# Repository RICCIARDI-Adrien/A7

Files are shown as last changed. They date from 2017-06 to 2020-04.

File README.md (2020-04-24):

# A7

A hand-made computer based on a 8-bit PIC18F26K22 microcontroller.

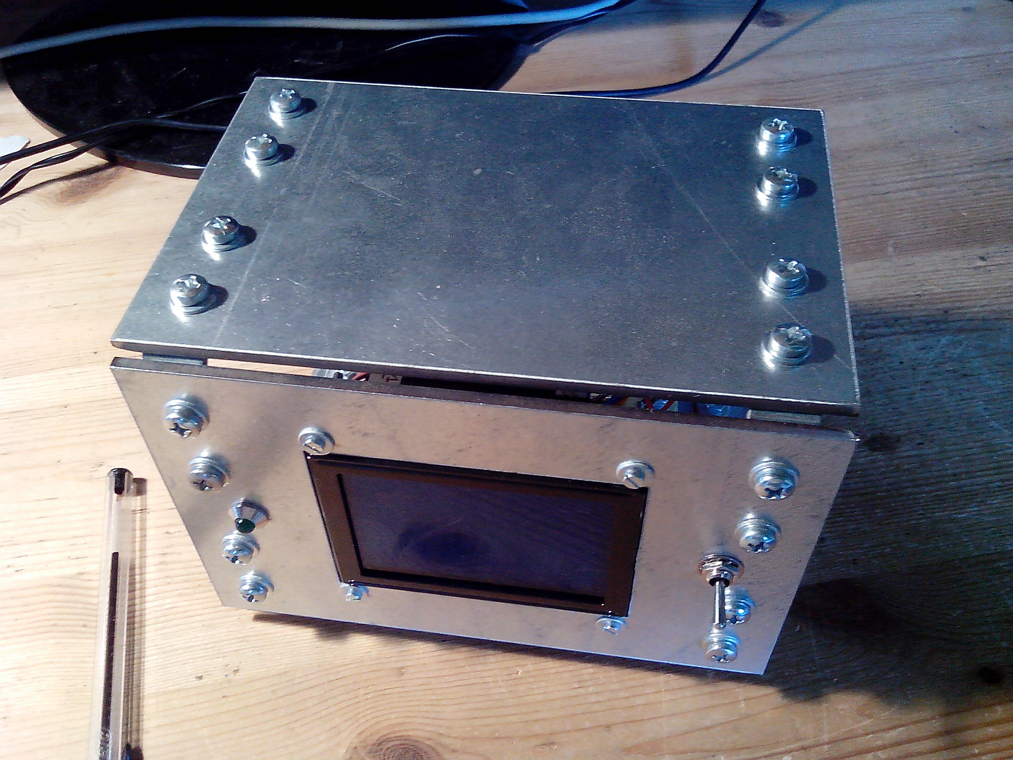
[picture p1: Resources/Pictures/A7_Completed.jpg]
A7


## Specifications

### CPU

* 64MHz PIC18 core (up to 16MIPS).
* 3896 RAM bytes.
* 32768 16-bit instruction words.

### Display

* 128x64 STN display with white pixels on blue backlight.
* 8-bit data interface with the microcontroller.

### Input

* Standard PS/2 keyboard support.
* Connect via standard PS/2 6-pin mini DIN connector.

### External storage

* On-board 128KB EEPROM (256-byte pages, 6ms maximum to write a page).
* Connected to a fast 4MHz SPI bus (less than 600us to read a full 256-byte page).

### Communication

* Standard RS-232 DB9 connector.
* Communication settings : 115200 bauds, no parity, one stop bit.

### Power supply

* Standard power supply jack.
* Input voltage from 7V to 24V with at least 200mA.
* Polarity reversal protection.

# Hardware

Schematics and PCB have been made with Eagle 7.5.  

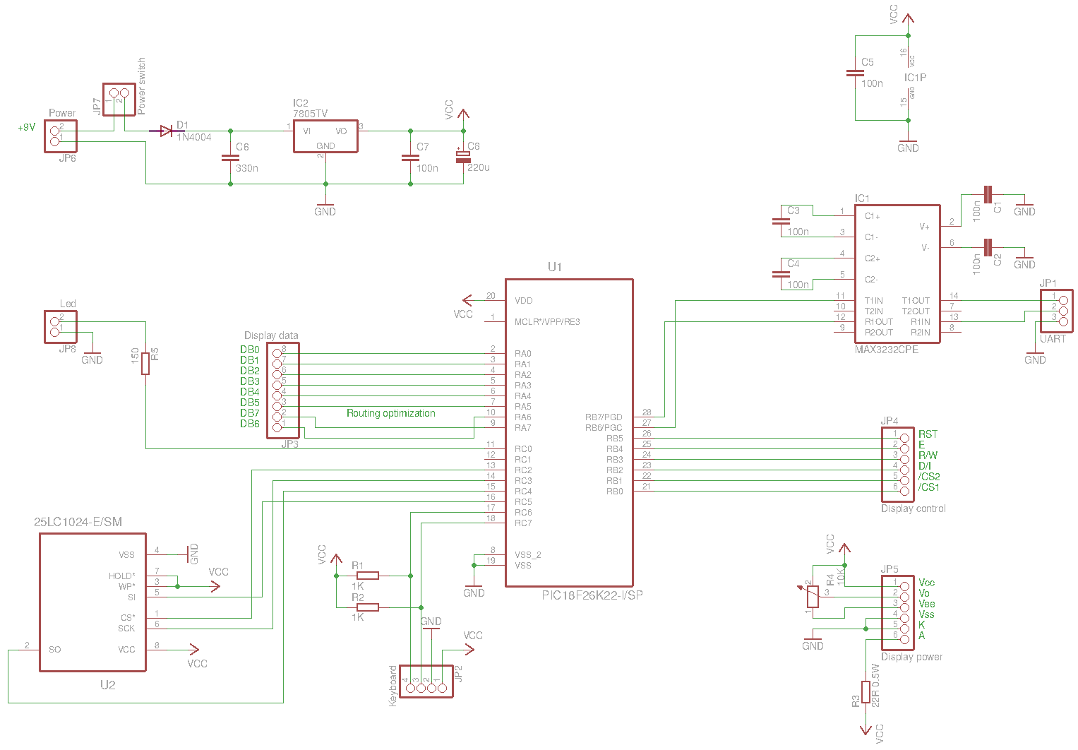
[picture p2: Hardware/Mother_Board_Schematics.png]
Motherboard schematics

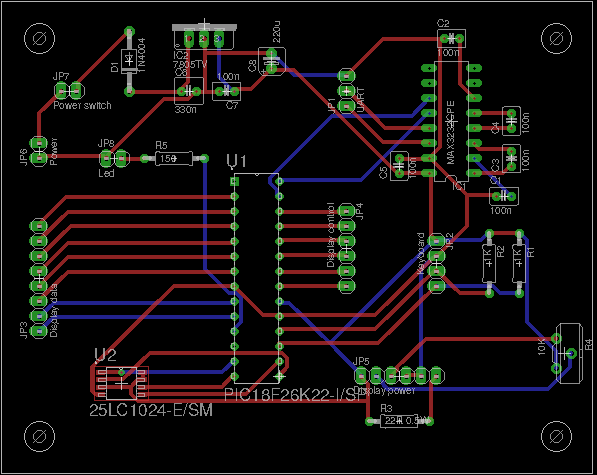
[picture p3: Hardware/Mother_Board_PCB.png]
Motherboard PCB


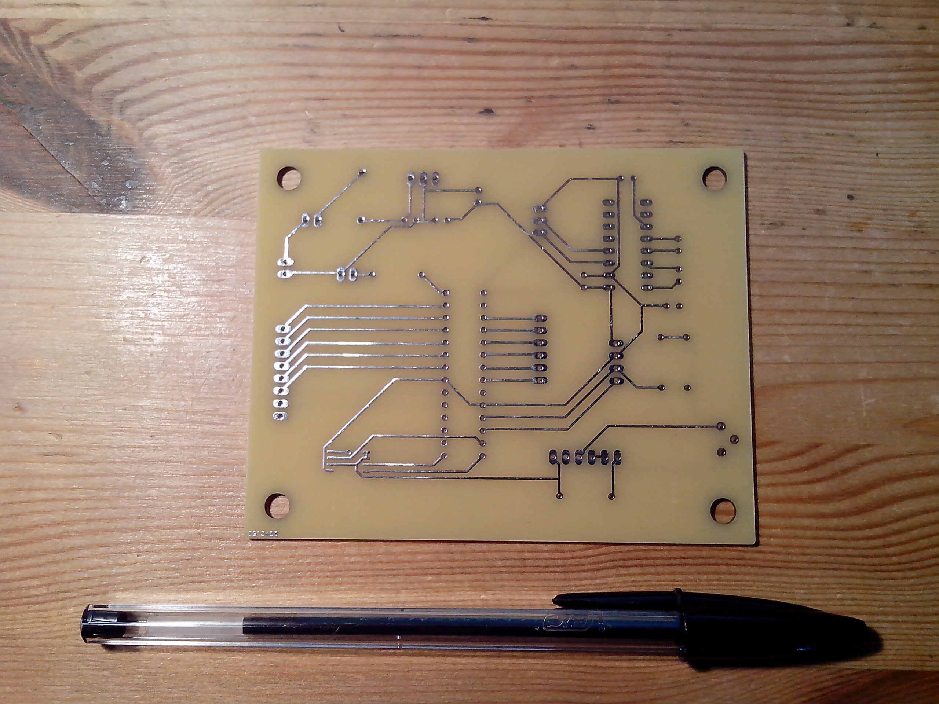
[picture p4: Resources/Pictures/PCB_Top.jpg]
Motherboard manufactured PCB (top view)

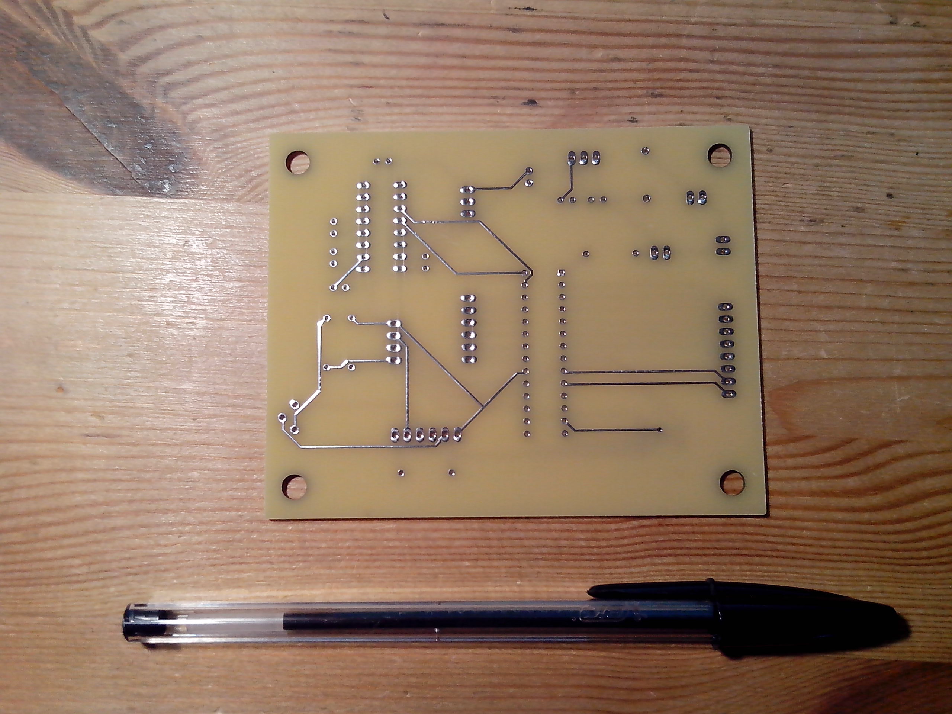
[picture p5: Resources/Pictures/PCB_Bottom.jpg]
Motherboard manufactured PCB (bottom view)

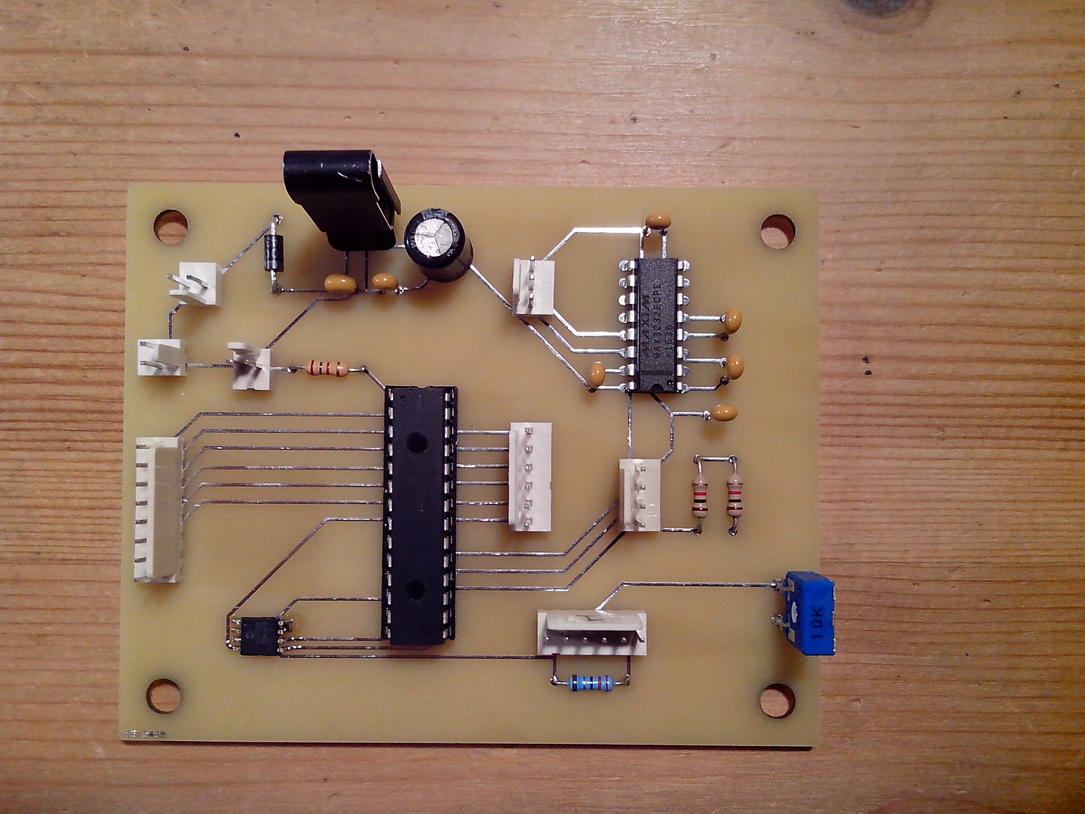
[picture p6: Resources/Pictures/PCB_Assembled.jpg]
Motherboard manufactured and assembled PCB


# Software

Use Microchip XC8 compiler to build software.  
You have to add the following environment variable for the build system to find the compiler-provided include files :
```
XC8_INCLUDES_PATH
```
The variable content must be the full path to the XC8 include directory. Below is an example for a Windows machine (don't forget to add quotation marks if the path contains spaces) :
```
"C:\Program Files\Microchip\xc8\v1.42\include"
```
  
In order to download applications on the A7, you have to set the following environment variable with the serial port device used to communicate with the A7 (like /dev/ttyS0, /dev/ttyUSB0...) :
```
A7_APPLICATION_DOWNLOAD_SERIAL_PORT_DEVICE
```

# Casing

Casing panels have been drawn with LibreCAD.

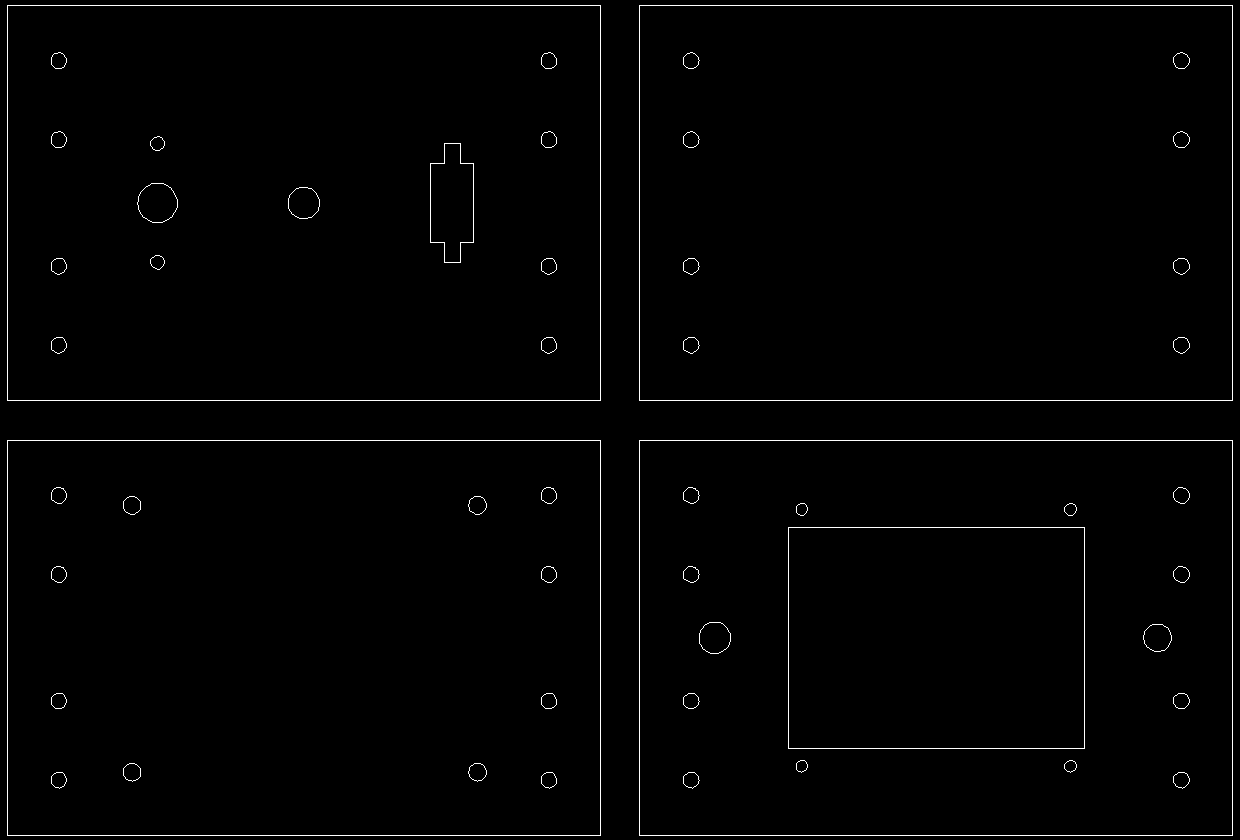
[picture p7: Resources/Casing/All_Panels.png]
Casing panels


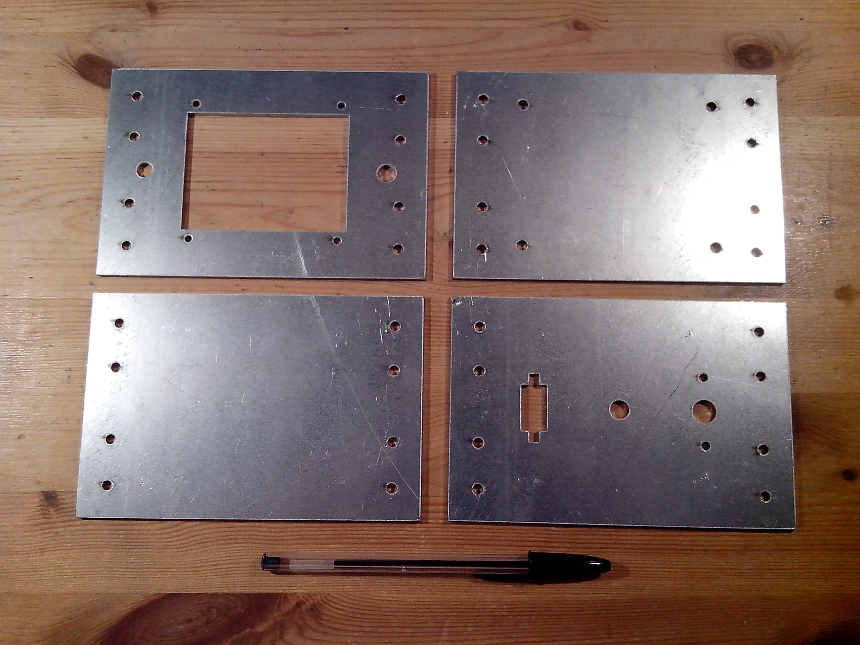
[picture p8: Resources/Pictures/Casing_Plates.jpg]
Casing plates

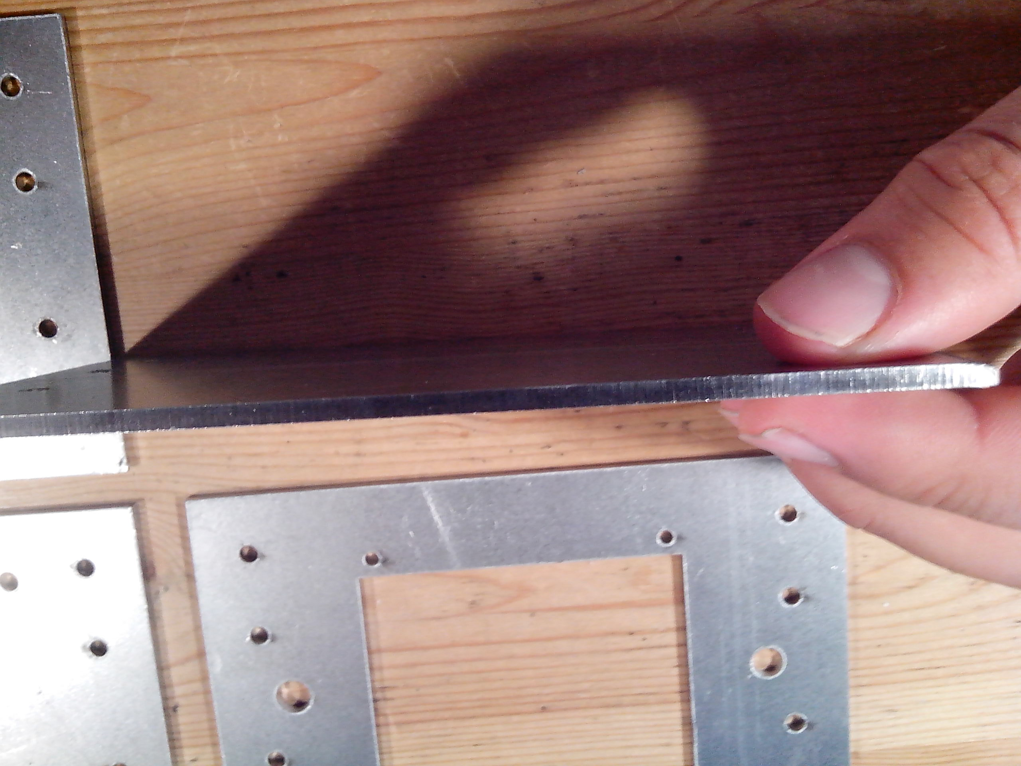
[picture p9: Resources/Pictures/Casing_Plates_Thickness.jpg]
Casing plates thickness


# Photo gallery

## 128x64 pixels graphical display

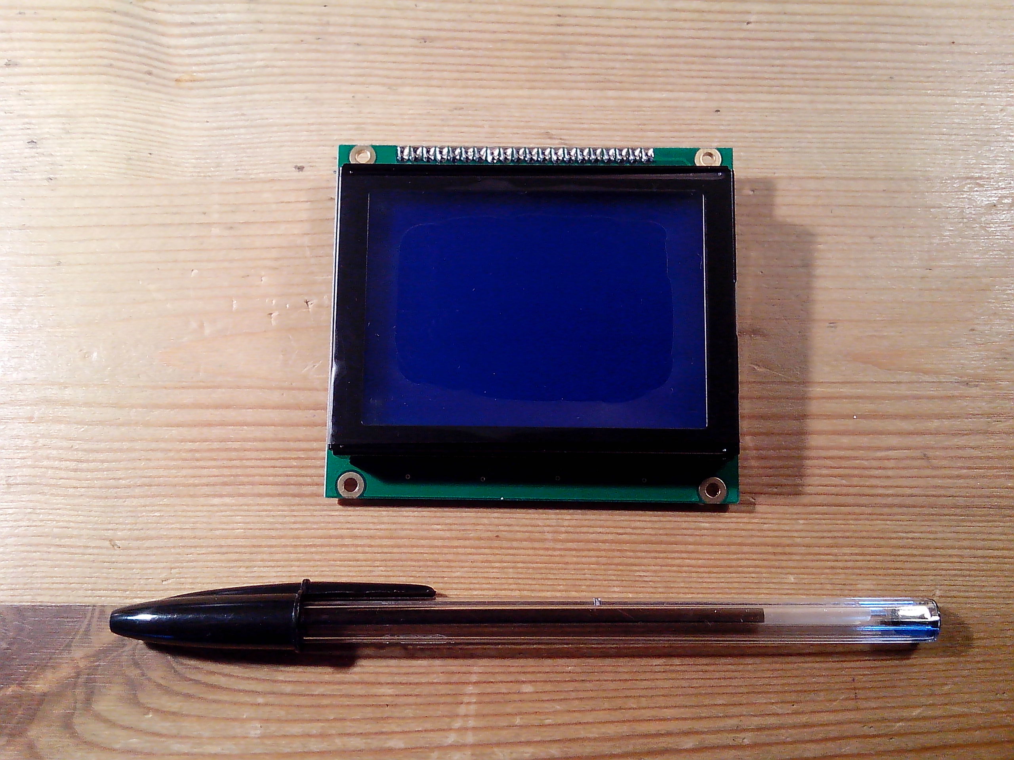
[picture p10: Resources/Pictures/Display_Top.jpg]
Display top

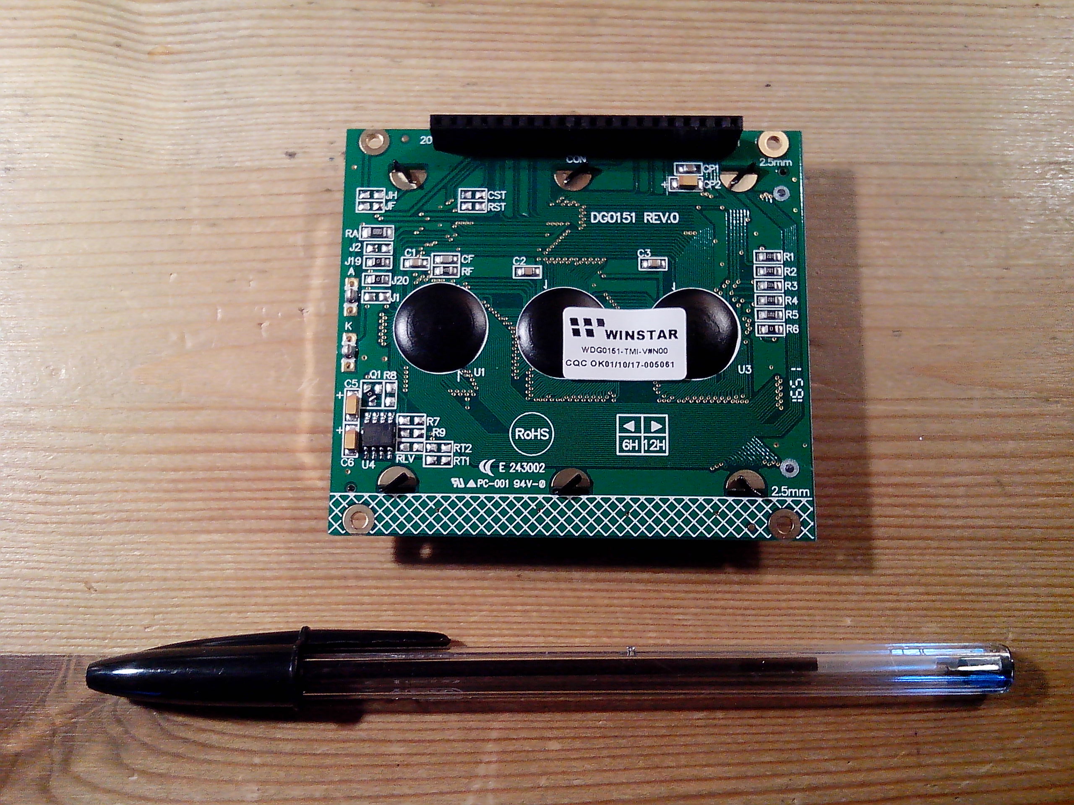
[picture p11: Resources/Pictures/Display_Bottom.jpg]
Display bottom


## Casing assembly

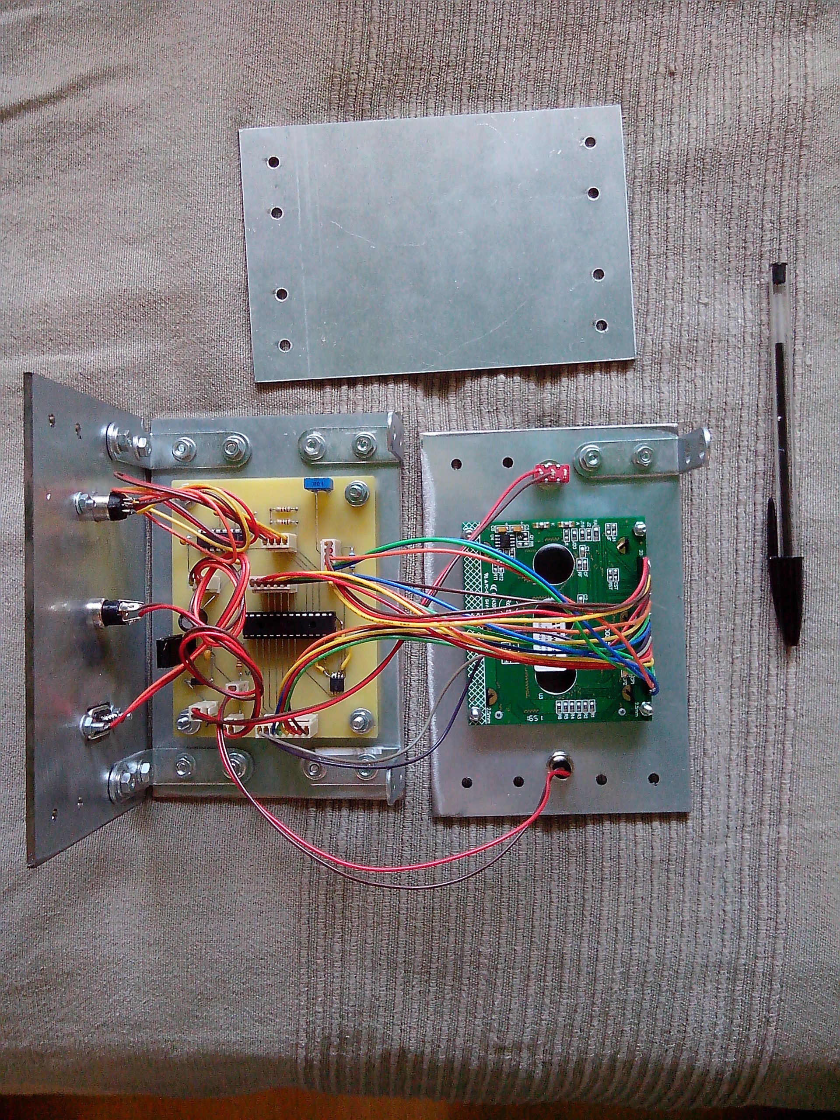
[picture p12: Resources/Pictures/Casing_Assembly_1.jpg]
Casing assembly 1

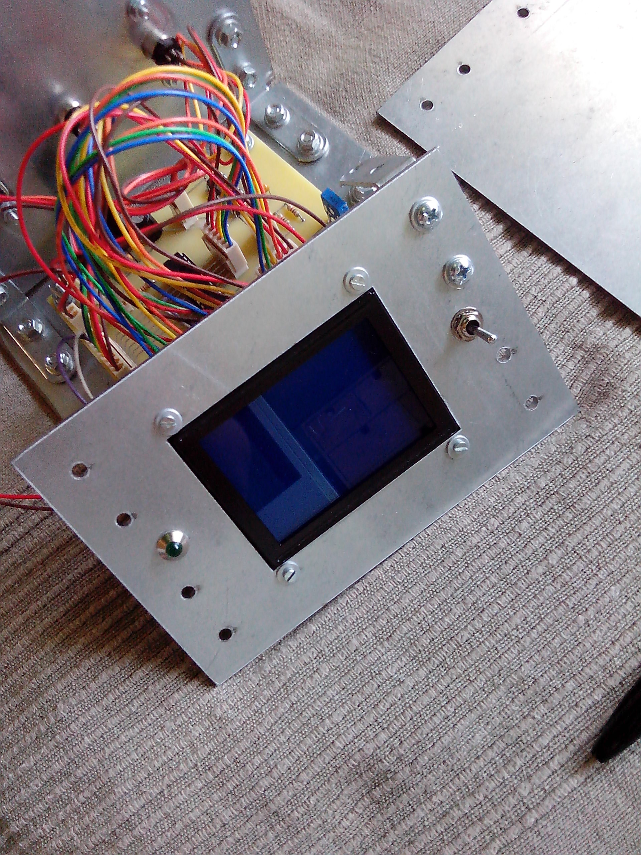
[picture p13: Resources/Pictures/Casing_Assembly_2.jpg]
Casing assembly 2


## Other viewing angles

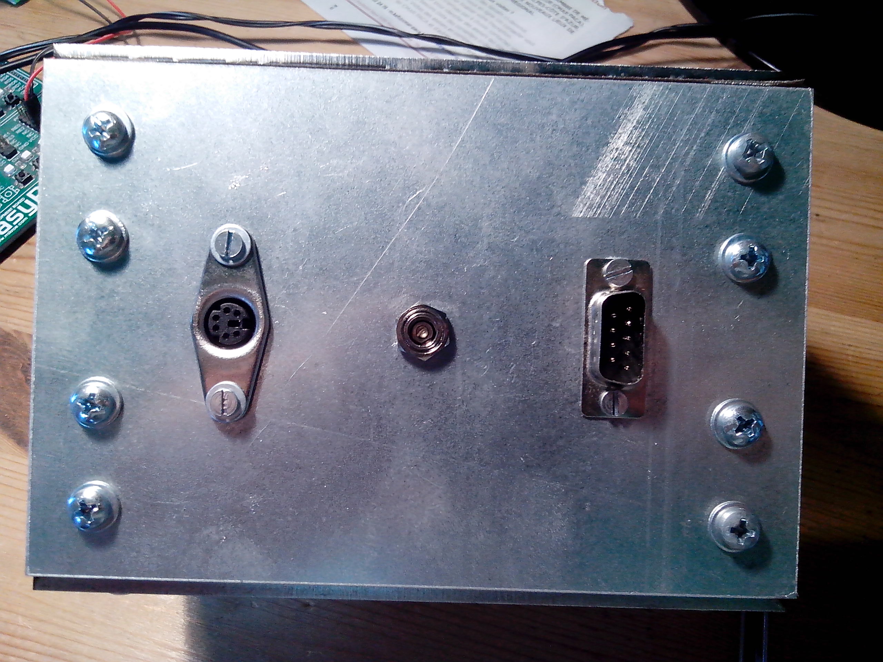
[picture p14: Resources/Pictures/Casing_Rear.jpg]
Casing rear

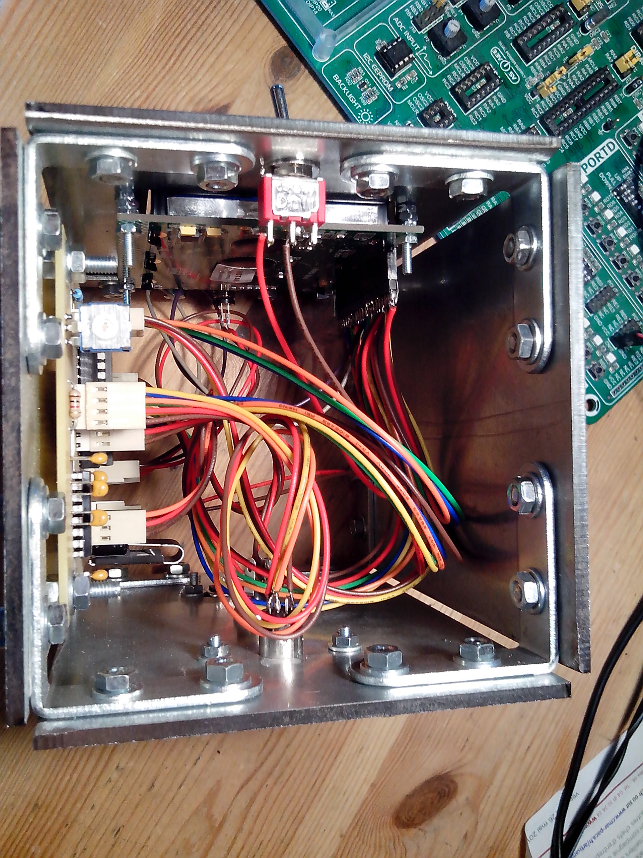
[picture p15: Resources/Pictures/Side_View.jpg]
Side view


## Booted operating system

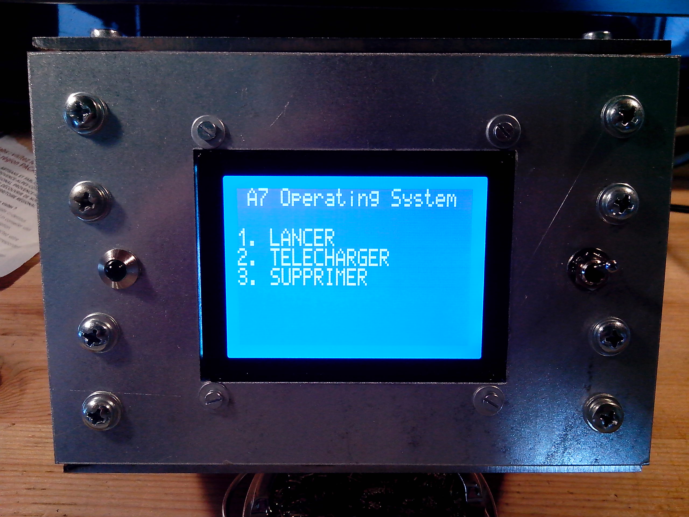
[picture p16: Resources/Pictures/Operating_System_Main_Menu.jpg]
Operating_System_Main_Menu


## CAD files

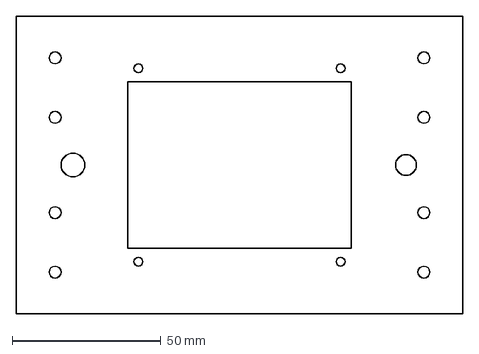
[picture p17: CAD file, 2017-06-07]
Resources/Casing/Front_Panel.dxf
150.0 x 100.0 mm

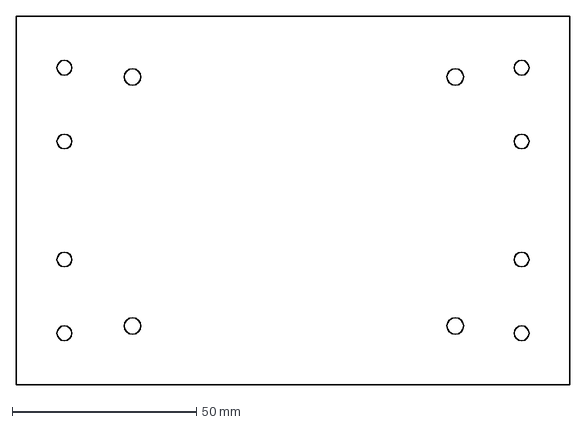
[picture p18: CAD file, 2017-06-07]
Resources/Casing/Bottom_Panel.dxf
150.0 x 100.0 mm

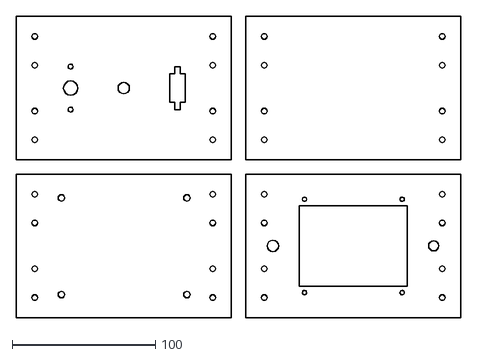
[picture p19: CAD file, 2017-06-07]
Resources/Casing/All_Panels.dxf
310.0 x 210.0

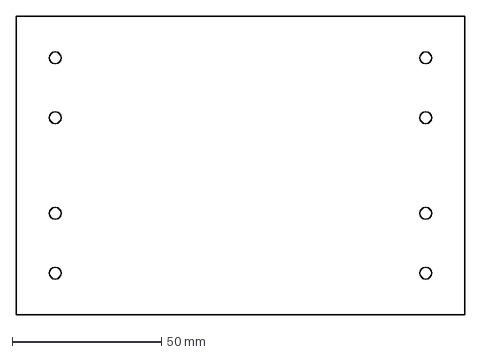
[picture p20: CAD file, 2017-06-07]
Resources/Casing/Top_Panel.dxf
150.0 x 100.0 mm

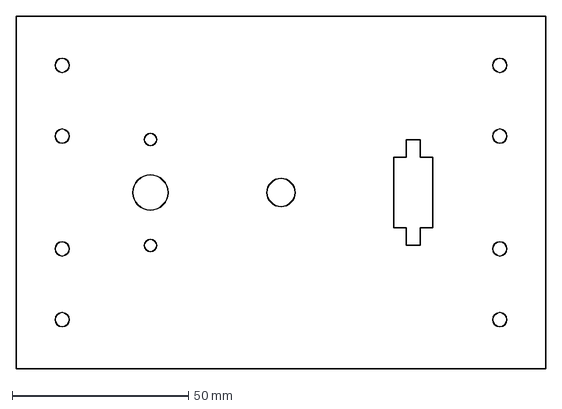
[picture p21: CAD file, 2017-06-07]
Resources/Casing/Rear_Panel.dxf
150.0 x 100.0 mm

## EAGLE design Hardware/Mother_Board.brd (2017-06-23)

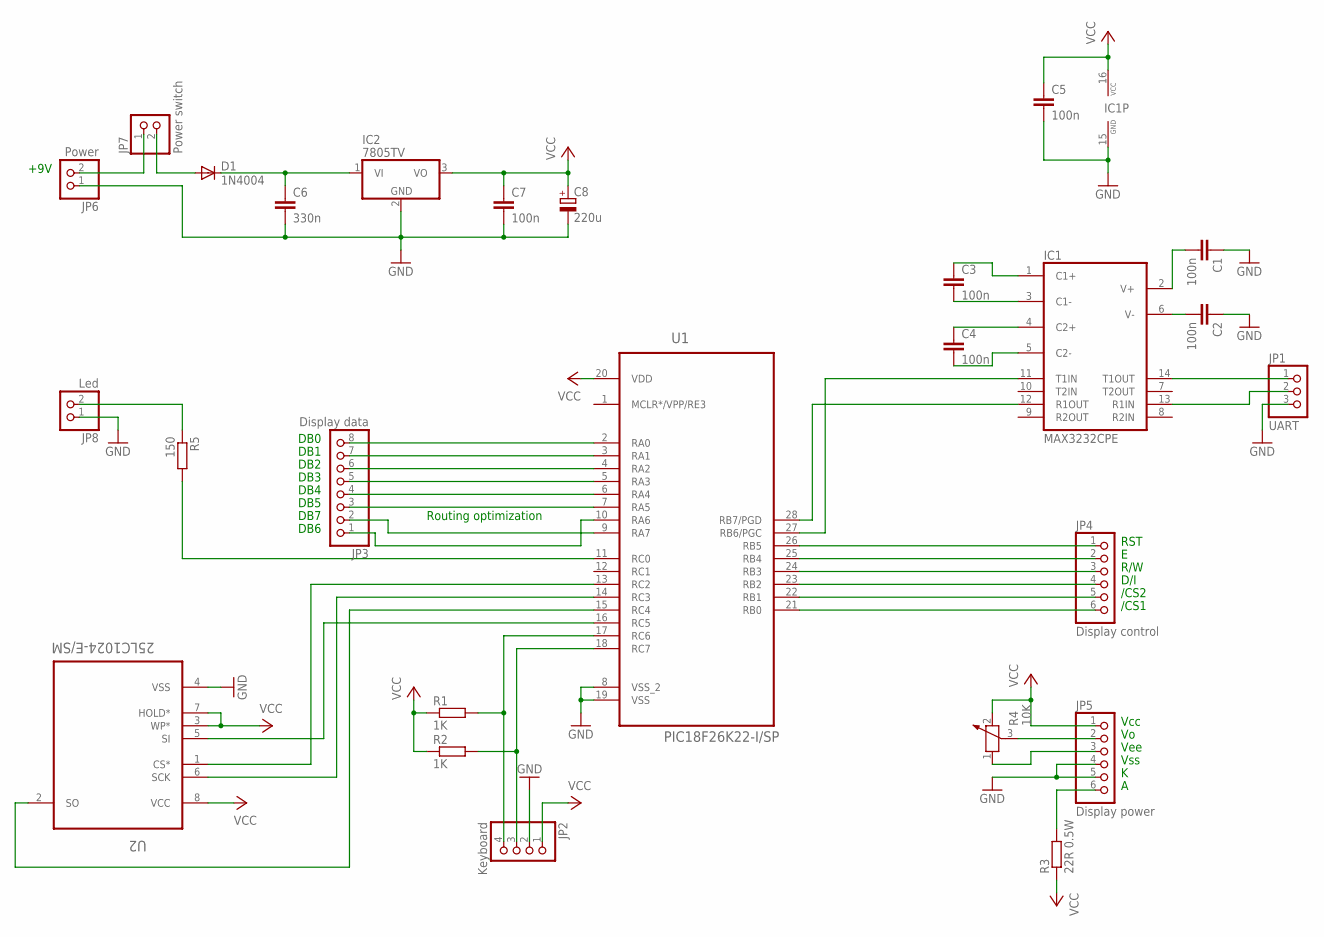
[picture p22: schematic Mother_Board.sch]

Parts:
C1, C2, C3, C4, C5, C7: 100n; C025-030X050
C6: 330n; C025-050X050
C8: 220u; B45181A
D1: 1N4004; DO41-10
IC1: MAX3232CPE; DIL16
IC2: 7805TV; TO220V
JP1: UART; 1X03
JP2: Keyboard; 1X04
JP3: Display data; 1X08
JP4: Display control; 1X06
JP5: Display power; 1X06
JP6: Power; 1X02
JP7: Power switch; 1X02
JP8: Led; 1X02
R1, R2: 1K; 0207/10
R3: 22R 0.5W; 0207/10
R4: 10K; PT-10S
R5: 150; 0207/10
U1: PIC18F26K22-I/SP; DIP254P762X508-28P
U2: 25LC1024-E/SM; SOIC127P794X203-8N

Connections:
GND: C1.1, C2.1, C5.2, C6.2, C7.2, C8.-, IC1.15 (GND), IC2.2 (GND), JP1.3, JP2.2, JP5.4, JP5.5, JP6.1, JP8.1, U1.8 (VSS_2), U1.19 (VSS), U2.4 (VSS)
unnamed: C3.1, IC1.1 (C1+)
unnamed: C3.2, IC1.3 (C1-)
unnamed: C4.1, IC1.4 (C2+)
unnamed: C4.2, IC1.5 (C2-)
unnamed: C1.2, IC1.2 (V+)
unnamed: IC1.12 (R1OUT), U1.28 (RB7/PGD)
unnamed: C2.2, IC1.6 (V-)
unnamed: IC1.11 (T1IN), U1.27 (RB6/PGC)
unnamed: IC1.14 (T1OUT), JP1.1
unnamed: IC1.13 (R1IN), JP1.2
unnamed: JP3.8, U1.2 (RA0)
unnamed: JP3.7, U1.3 (RA1)
unnamed: JP2.3, R2.2, U1.18 (RC7)
unnamed: JP2.4, R1.2, U1.17 (RC6)
unnamed: JP3.6, U1.4 (RA2)
unnamed: JP3.5, U1.5 (RA3)
unnamed: JP3.4, U1.6 (RA4)
unnamed: JP3.3, U1.7 (RA5)
unnamed: JP3.2, U1.9 (RA7)
unnamed: JP3.1, U1.10 (RA6)
unnamed: U1.16 (RC5), U2.5 (SI)
unnamed: U1.14 (RC3), U2.6 (SCK)
unnamed: U1.15 (RC4), U2.2 (SO)
unnamed: U1.13 (RC2), U2.1 (CS*)
unnamed: JP5.3, R4.1
unnamed: JP4.1, U1.26 (RB5)
unnamed: JP4.2, U1.25 (RB4)
unnamed: JP4.3, U1.24 (RB3)
unnamed: JP4.4, U1.23 (RB2)
unnamed: JP4.5, U1.22 (RB1)
unnamed: JP4.6, U1.21 (RB0)
unnamed: JP5.2, R4.3
unnamed: JP5.6, R3.2
unnamed: JP6.2, JP7.1
unnamed: D1.A, JP7.2
unnamed: C6.1, D1.C, IC2.1 (VI)
unnamed: R5.2, U1.11 (RC0)
unnamed: JP8.2, R5.1
VCC: C5.1, C7.1, C8.+, IC1.16 (VCC), IC2.3 (VO), JP2.1, JP5.1, R1.1, R2.1, R3.1, R4.2, U1.20 (VDD), U2.3 (WP*), U2.7 (HOLD*), U2.8 (VCC)

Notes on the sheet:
DB0
DB1
DB2
DB3
DB4
DB5
DB6
DB7
Vcc
Vee
Vss
/CS1
/CS2
D/I
R/W
RST
+9V
Routing optimization

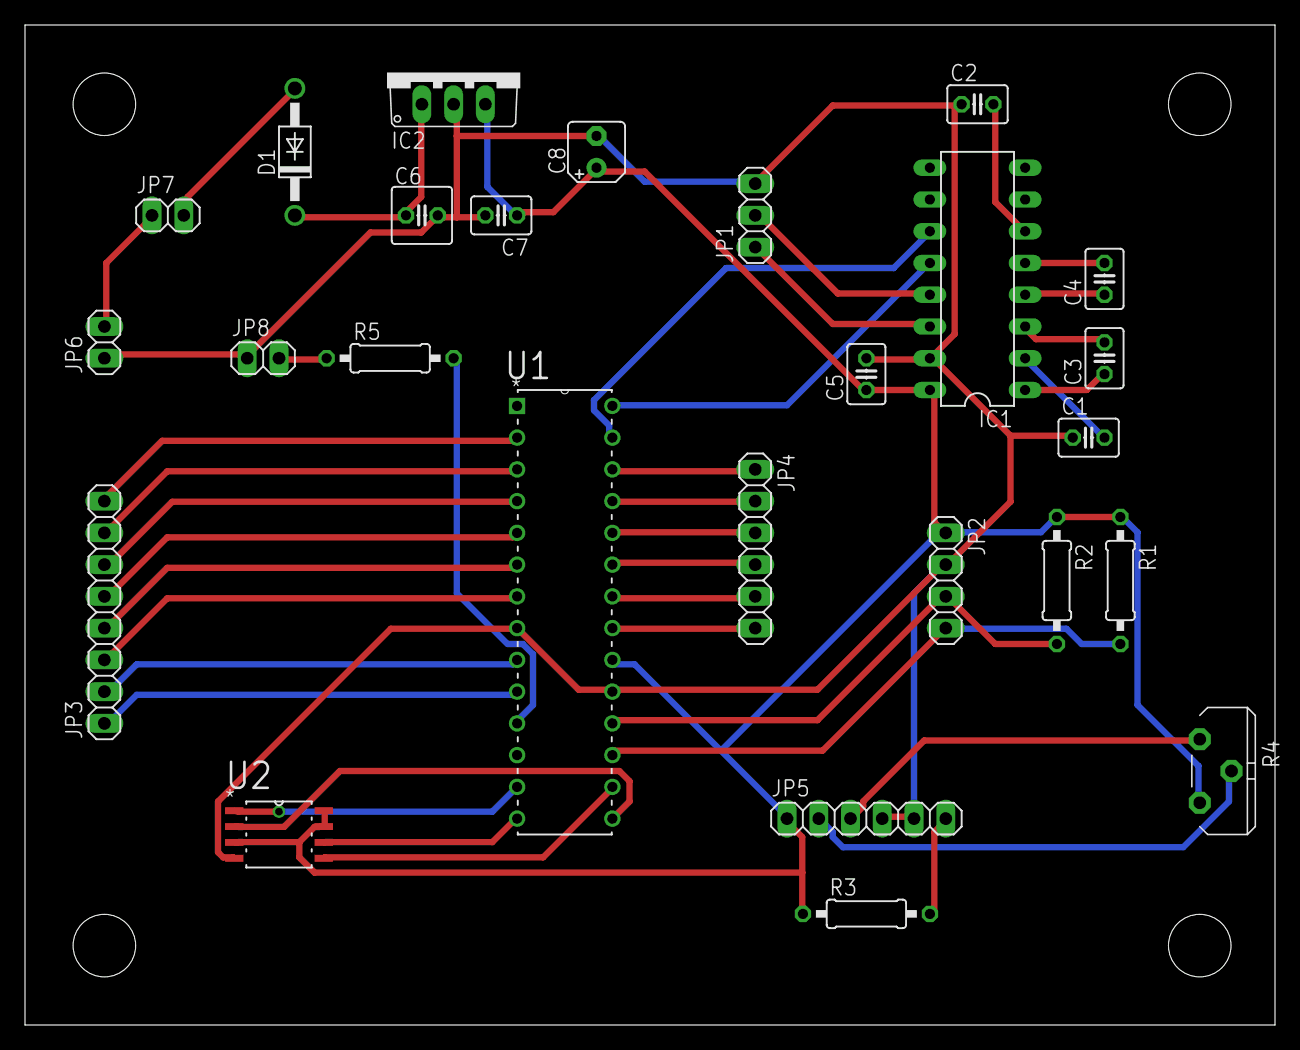
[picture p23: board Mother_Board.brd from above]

Board: 2 copper layers, 100.0 x 80.0 mm, 26 parts (0 on the bottom side), 40 nets.

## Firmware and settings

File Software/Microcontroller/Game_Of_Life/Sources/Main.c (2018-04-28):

/** @file Main.c
 * Conway famous cellular automaton.
 * @author Adrien RICCIARDI
 */
#include <string.h>
#include <System.h>

//-------------------------------------------------------------------------------------------------
// Private constants
//-------------------------------------------------------------------------------------------------
/** How many cells on a row. */
#define MAIN_WORLD_WIDTH_CELLS 64
/** How many cells on a column. */
#define MAIN_WORLD_HEIGHT_CELLS 32

/** How many RAM a world requires. */
#define MAIN_WORLD_SIZE_BYTES ((MAIN_WORLD_WIDTH_CELLS * MAIN_WORLD_HEIGHT_CELLS) / 8) // Divide by 8 because cell states are stored on a single bit

/** Cell sprite width in pixels. */
#define MAIN_CELL_SPRITE_WIDTH_PIXELS 2
/** Cell sprite height in pixels. */
#define MAIN_CELL_SPRITE_HEIGHT_PIXELS 2

/** How many generations are kept to check for hanged worlds. */
#define MAIN_WORLD_GENERATIONS_COUNT 7

//-------------------------------------------------------------------------------------------------
// Private variables
//-------------------------------------------------------------------------------------------------
/** A cell sprite (a 2x2 pixels square). */
static const unsigned char Main_Cell_Sprite[] = { 0x03, 0x03 };

/** Useful world generations. */
static unsigned char Main_World_Generations[MAIN_WORLD_GENERATIONS_COUNT][MAIN_WORLD_SIZE_BYTES]; // Current generation is index 0

//-------------------------------------------------------------------------------------------------
// Private functions
//-------------------------------------------------------------------------------------------------
/** Get the specified cell state (dead or alive).
 * @param Pointer_World The world the cell belongs to.
 * @param Row The cell vertical coordinate.
 * @param Column The cell horizontal coordinate.
 * @return 0 if the cell is dead,
 * @return 1 if the cell is alive.
 */
static unsigned char MainGetCellState(unsigned char *Pointer_World, unsigned char Row, unsigned char Column)
{
	unsigned char Cells_State, Is_Cell_Alive, Bit_Index;
	
	// Retrieve the byte the cells are stored in
	Cells_State = Pointer_World[((Row * MAIN_WORLD_WIDTH_CELLS) + Column) >> 3]; // Fast divide by 8 by doing a shift
	
	// Extract the requested bit
	Bit_Index = Column & 0x07; // Ultrafast modulo 8 operation
	if (Cells_State & (1 << Bit_Index)) Is_Cell_Alive = 1;
	else Is_Cell_Alive = 0;
	
	return Is_Cell_Alive;
}

/** Set the specified cell state.
 * @param Pointer_World The world the cell belongs to.
 * @param Row The cell vertical coordinate.
 * @param Column The cell horizontal coordinate.
 * @param Is_Cell_Alive Set to 1 if the cell is alive, set to 0 if the cell is dead.
 */
static void MainSetCellState(unsigned char *Pointer_World, unsigned char Row, unsigned char Column, unsigned char Is_Cell_Alive)
{
	unsigned char Cells_State, Bit_Index;
	unsigned short Cells_State_Index;
	
	// Retrieve the byte the cells are stored in
	Cells_State_Index = ((Row * MAIN_WORLD_WIDTH_CELLS) + Column) >> 3; // Fast divide by 8 by doing a shift
	Cells_State = Pointer_World[Cells_State_Index];
	
	// Set the new cell state
	Bit_Index = Column & 0x07; // Ultrafast modulo 8 operation
	if (Is_Cell_Alive) Cells_State |= 1 << Bit_Index;
	else Cells_State &= ~(1 << Bit_Index);
	Pointer_World[Cells_State_Index] = Cells_State;
}

/** Generate a random world. */
static inline void MainGenerateWorld(void)
{
	unsigned char Row, Column, Random_Value, Is_Cell_Alive;
	
	// Reset previous generations to be sure they won't match with the newly generated world
	for (Row = 1; Row < MAIN_WORLD_GENERATIONS_COUNT; Row++) memset(Main_World_Generations[Row], 0, MAIN_WORLD_SIZE_BYTES); // Recycle "Row" variable
	
	// Generate a new current world
	for (Row = 0; Row < MAIN_WORLD_HEIGHT_CELLS; Row++)
	{
		for (Column = 0; Column < MAIN_WORLD_WIDTH_CELLS; Column++)
		{
			// There is a chance out of 8 to get an alive cell
			Random_Value = SystemRandomGetNumber() & 0x07; // Ultrafast modulo 8 operation
			if (Random_Value == 2) Is_Cell_Alive = 1;
			else Is_Cell_Alive = 0;
			
			MainSetCellState(Main_World_Generations[0], Row, Column, Is_Cell_Alive);
		}
	}
}

/** Apply game of life rules on the current generation and generate the next generation (still stored in Main_World_Current_Generation array). */
static inline void MainComputeNextGeneration(void)
{
	static unsigned char World_Next_Generation[MAIN_WORLD_SIZE_BYTES];
	unsigned char Row, Column, Neighbor_Cells_Count, Is_Cell_Alive, *Pointer_World_Current_Generation = Main_World_Generations[0];
	
	SystemLedOn();
	
	// Save previous generations (replace the oldest one by the old one and so on)
	for (Row = MAIN_WORLD_GENERATIONS_COUNT - 1; Row > 0; Row--) memcpy(Main_World_Generations[Row], Main_World_Generations[Row - 1], MAIN_WORLD_SIZE_BYTES); // Recycle "Row" variable
	
	// Handle all current world cells
	for (Row = 0; Row < MAIN_WORLD_HEIGHT_CELLS; Row++)
	{
		for (Column = 0; Column < MAIN_WORLD_WIDTH_CELLS; Column++)
		{
			// Compute how many alive neighbors a cell has
			Neighbor_Cells_Count = 0;
			// North-west from the current cell
			if ((Row > 0) && (Column > 0)) Neighbor_Cells_Count += MainGetCellState(Pointer_World_Current_Generation, Row - 1, Column - 1);
			// North from the current cell
			if (Row > 0) Neighbor_Cells_Count += MainGetCellState(Pointer_World_Current_Generation, Row - 1, Column);
			// North-east from the current cell
			if ((Row > 0) && (Column < MAIN_WORLD_WIDTH_CELLS - 1)) Neighbor_Cells_Count += MainGetCellState(Pointer_World_Current_Generation, Row - 1, Column + 1);
			// West from the current cell
			if (Column > 0) Neighbor_Cells_Count += MainGetCellState(Pointer_World_Current_Generation, Row, Column - 1);
			// East from the current cell
			if (Column < MAIN_WORLD_WIDTH_CELLS - 1) Neighbor_Cells_Count += MainGetCellState(Pointer_World_Current_Generation, Row, Column + 1);
			// South-west from the current cell
			if ((Row < MAIN_WORLD_HEIGHT_CELLS - 1) && (Column > 0)) Neighbor_Cells_Count += MainGetCellState(Pointer_World_Current_Generation, Row + 1, Column - 1);
			// South from the current cell
			if (Row < MAIN_WORLD_HEIGHT_CELLS - 1) Neighbor_Cells_Count += MainGetCellState(Pointer_World_Current_Generation, Row + 1, Column);
			// South-east from the current cell
			if ((Row < MAIN_WORLD_HEIGHT_CELLS - 1) && (Column < MAIN_WORLD_WIDTH_CELLS - 1)) Neighbor_Cells_Count += MainGetCellState(Pointer_World_Current_Generation, Row + 1, Column + 1);
			
			// A cell is born if there are exactly 3 alive neighbors
			if (Neighbor_Cells_Count == 3) Is_Cell_Alive = 1;
			// Cell stays in its current state if it has exactly 2 alive neighbors
			else if (Neighbor_Cells_Count == 2) Is_Cell_Alive = MainGetCellState(Pointer_World_Current_Generation, Row, Column);
			// In all other case an alive cell dies, or a yet-died cell does not return to life
			else Is_Cell_Alive = 0;
			
			// Store new cell state
			MainSetCellState(World_Next_Generation, Row, Column, Is_Cell_Alive);
		}
	}
	
	// Next generation is fully generated, copy it to the current one
	memcpy(Pointer_World_Current_Generation, World_Next_Generation, MAIN_WORLD_SIZE_BYTES);
	
	SystemLedOff();
}

/** Check if the current world can evolve or if it is stuck in an infinite loop.
 * @return 0 if the world can't evolve anymore,
 * @return 1 if the world is still evolving.
 */
static inline unsigned char MainIsWorldEvolving(void)
{
	// Checking if current and previous generations are the same allows to detect a completely hanged world (this also works by checking with current and before last generations, and allows to display the stuck world). Checking current against before last generations allows to detect 2-period oscillators
	if (memcmp(Main_World_Generations[0], Main_World_Generations[2], MAIN_WORLD_SIZE_BYTES) == 0) return 0;
	
	// Three-period oscillators and 2-period ones are synchronized only one time out of six, so we have to check the current generation against the older 6th to discard 3-period oscillators
	if (memcmp(Main_World_Generations[0], Main_World_Generations[6], MAIN_WORLD_SIZE_BYTES) == 0) return 0;
	
	return 1;
}

/** Display the world current generation. */
static inline void MainDisplayWorld(void)
{
	unsigned char Cell_Row, Cell_Column, Sprite_Row = 0, Sprite_Column = 0;
	
	SystemDisplayClear();
	
	for (Cell_Row = 0; Cell_Row < MAIN_WORLD_HEIGHT_CELLS; Cell_Row++)
	{
		for (Cell_Column = 0; Cell_Column < MAIN_WORLD_WIDTH_CELLS; Cell_Column++)
		{
			// Display the sprite only if the cell is alive
			if (MainGetCellState(Main_World_Generations[0], Cell_Row, Cell_Column)) SystemDisplayRenderSprite(Sprite_Column, Sprite_Row, Main_Cell_Sprite, MAIN_CELL_SPRITE_WIDTH_PIXELS, MAIN_CELL_SPRITE_HEIGHT_PIXELS);
			
			// Update sprite coordinates
			Sprite_Column += MAIN_CELL_SPRITE_WIDTH_PIXELS;
		}
		
		// Make sprite coordinate go to next row
		Sprite_Row += MAIN_CELL_SPRITE_HEIGHT_PIXELS;
		Sprite_Column = 0;
	}
	
	SystemDisplayUpdate();
}

//-------------------------------------------------------------------------------------------------
// Entry point
//-------------------------------------------------------------------------------------------------
void main(void)
{
	unsigned char Key, Is_Fast_Mode_Enabled = 0;
	
	SystemInitialize();
	
	while (1)
	{
		// Generate a new world
		MainGenerateWorld();
		
		while (1)
		{
			// Check if the user hit a key
			if (SystemKeyboardIsKeyAvailable())
			{
				Key = SystemKeyboardReadCharacter();
				
				// Exit program if "escape" key is pressed
				if (Key == SYSTEM_KEYBOARD_KEY_CODE_ESCAPE) SystemExitProgram();
				// Generate a new world if the 'n' key is pressed
				if (Key == 'n') break;
				// Toggle fast mode
				if (Key == 'f')
				{
					if (Is_Fast_Mode_Enabled) Is_Fast_Mode_Enabled = 0;
					else Is_Fast_Mode_Enabled = 1;
				}
			}
			
			// Show world state (show it before computing the next generation to see what the generated world looks like)
			MainDisplayWorld();
			
			// Simulate world
			MainComputeNextGeneration();
			
			// Generate a new world if this one is stuck
			if (!MainIsWorldEvolving()) break;
			
			// Wait a bit to let the watchers understand what is happening
			if (!Is_Fast_Mode_Enabled) __delay_ms(250);
		}
	}
}

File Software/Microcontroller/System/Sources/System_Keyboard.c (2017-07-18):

/** @file System_Keyboard.c
 * See System_Keyboard.h for description.
 * @author Adrien RICCIARDI
 */
#include <System.h> // Needed for the clock frequency constant
#include <System_Keyboard.h>
#include <xc.h>

//-------------------------------------------------------------------------------------------------
// Private variables
//-------------------------------------------------------------------------------------------------
/** The last received character. */
static unsigned char System_Keyboard_Received_Character;
/** Tell if a new unread key is available. */
static volatile unsigned char System_Keyboard_Is_Key_Available = 0;

/** Maintain a bit map telling which "game" keys are pressed and which are released. */
static volatile unsigned char System_Keyboard_Game_Keys_State_Bit_Mask = 0;

/** Characters issued when no modifier key is pressed (AZERTY mapping). */
static unsigned char System_Keyboard_Lowercase_Characters[] =
{
	0, // Offset 0
	SYSTEM_KEYBOARD_KEY_CODE_F9, // Offset 0x01
	0, // Offset 0x02
	SYSTEM_KEYBOARD_KEY_CODE_F5, // Offset 0x03
	SYSTEM_KEYBOARD_KEY_CODE_F3, // Offset 0x04
	SYSTEM_KEYBOARD_KEY_CODE_F1, // Offset 0x05
	SYSTEM_KEYBOARD_KEY_CODE_F2, // Offset 0x06
	SYSTEM_KEYBOARD_KEY_CODE_F12, // Offset 0x07
	0, // Offset 0x08
	SYSTEM_KEYBOARD_KEY_CODE_F10, // Offset 0x09
	SYSTEM_KEYBOARD_KEY_CODE_F8, // Offset 0x0A
	SYSTEM_KEYBOARD_KEY_CODE_F6, // Offset 0x0B
	SYSTEM_KEYBOARD_KEY_CODE_F4, // Offset 0x0C
	'\t', // Offset 0x0D
	'`', // Offset 0x0E
	0, // Offset 0x0F
	0, // Offset 0x10
	SYSTEM_KEYBOARD_KEY_CODE_LEFT_ALT, // 0x11
	0, // 0x12
	0, // Offset 0x13
	SYSTEM_KEYBOARD_KEY_CODE_LEFT_CONTROL, // Offset 0x14
	'a', // Offset 0x15
	'&', // Offset 0x16
	0, // Offset 0x17
	0, // Offset 0x18
	0, // Offset 0x19
	'w', // Offset 0x1A
	's', // Offset 0x1B
	'q', // Offset 0x1C
	'z', // Offset 0x1D
	'\202', // Offset 0x1E
	0, // Offset 0x1F (TODO E0, no confict)
	0, // Offset 0x20
	'c', // Offset 0x21
	'x', // Offset 0x22
	'd', // Offset 0x23
	'e', // Offset 0x24
	'\'', // Offset 0x25
	'\"', // Offset 0x26
	0, // Offset 0x27 (TODO E0, no conflict)
	0, // Offset 0x28
	' ', // Offset 0x29
	'v', // Offset 0x2A
	'f', // Offset 0x2B
	't', // Offset 0x2C
	'r', // Offset 0x2D
	'(', // Offset 0x2E
	0, // Offset 0x2F (TODO E0, no conflict, DO NOT MAP (mouse right-click menu key)
	0, // Offset 0x30
	'n', // Offset 0x31
	'b', // Offset 0x32
	'h', // Offset 0x33
	'g', // Offset 0x34
	'y', // Offset 0x35
	'-', // Offset 0x36
	0, // Offset 0x37
	0, // Offset 0x38
	0, // Offset 0x39
	',', // Offset 0x3A
	'j', // Offset 0x3B
	'u', // Offset 0x3C
	'\212', // Offset 0x3D
	'_', // Offset 0x3E
	0, // Offset 0x3F
	0, // Offset 0x40
	';', // Offset 0x41
	'k', // Offset 0x42
	'i', // Offset 0x43
	'o', // Offset 0x44
	'\205', // Offset 0x45
	'\135', // Offset 0x46
	0, // Offset 0x47
	0, // Offset 0x48
	':', // Offset 0x49
	'!', // Offset 0x4A
	'l', // Offset 0x4B
	'm', // Offset 0x4C
	'p', // Offset 0x4D
	')', // Offset 0x4E
	0, // Offset 0x4F
	0, // Offset 0x50
	0, // Offset 0x51
	'\227', // Offset 0x52
	0, // Offset 0x53
	'^', // Offset 0x54
	'=', // Offset 0x55
	0, // Offset 0x56
	0, // Offset 0x57
	SYSTEM_KEYBOARD_KEY_CODE_CAPITALS_LOCK, // Offset 0x58
	0, // Offset 0x59 (TODO right shift)
	'\n', // Offset 0x5A
	'$', // Offset 0x5B
	0, // Offset 0x5C
	'*', // Offset 0x5D
	0, // Offset 0x5E
	0, // Offset 0x5F
	0, // Offset 0x60
	0, // Offset 0x61
	0, // Offset 0x62
	0, // Offset 0x63
	0, // Offset 0x64
	0, // Offset 0x65
	'\b', // Offset 0x66
	0, // Offset 0x67
	0, // Offset 0x68
	'1', // Offset 0x69 (TODO also END)
	0, // Offset 0x6A
	'4', // Offset 0x6B (TODO also left arrow)
	'7', // Offset 0x6C (TODO also HOME)
	0, // Offset 0x6D
	0, // Offset 0x6E
	0, // Offset 0x6F
	'0', // Offset 0x70 (TODO also INSERT)
	'.', // Offset 0x71 (TODO also DELETE)
	'2', // Offset 0x72 (TODO also down arrow)
	'5', // Offset 0x73
	'6', // Offset 0x74 (TODO also right arrow)
	'8', // Offset 0x75 (TODO also up arrow)
	SYSTEM_KEYBOARD_KEY_CODE_ESCAPE, // Offset 0x76
	0, // Offset 0x77
	SYSTEM_KEYBOARD_KEY_CODE_F11, // Offset 0x78
	'+', // Offset 0x79
	'3', // Offset 0x7A (TODO also PAGE DOWN)
	'-', // Offset 0x7B
	'*', // Offset 0x7C
	'9', // Offset 0x7D (TODO also PAGE UP)
	0, // Offset 0x7E
	0 // Offset 0x7F
};
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

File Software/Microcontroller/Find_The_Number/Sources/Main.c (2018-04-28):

/** @file Main.c
 * A simple game using dichotomy to find an unknown number.
 * @author Adrien RICCIARDI
 */
#include <stdlib.h>
#include <string.h>
#include <Strings.h>
#include <System.h>

//-------------------------------------------------------------------------------------------------
// Private constants
//-------------------------------------------------------------------------------------------------
/** How many digits are allowed for the number read from the keyboard. */
#define NUMBER_MAXIMUM_DIGITS_COUNT 9 // Maximum amount of digits that can be stored on a 4-byte integer.

/** How many times the player can try to win. */
#define PLAYER_MAXIMUM_ATTEMPTS_COUNT 28 // A computer would need log2(1000000000) = 29.9 attempts to win, make it harder for a human

//-------------------------------------------------------------------------------------------------
// Private functions
//-------------------------------------------------------------------------------------------------
/** Generate the number the player will have to find.
 * @param String_Number On output, contain the number converted to string. Make sure the buffer is at least NUMBER_MAXIMUM_DIGITS_COUNT + 1 bytes large.
 */
static inline void MainGenerateRandomNumber(unsigned char *String_Number)
{
	unsigned char i, Random_Digit;
	
	for (i = 0; i < NUMBER_MAXIMUM_DIGITS_COUNT; i++)
	{
		Random_Digit = SystemRandomGetNumber() % 10;
		String_Number[i] = Random_Digit + 48; // Convert number to ASCII representation
	}
	// Terminate string
	String_Number[NUMBER_MAXIMUM_DIGITS_COUNT] = 0;
}

/** Read a number from the keyboard. Only digits, enter and backspace keys are accepted.
 * @param String_Number On output, contain the read number converted to a string. Make sure the provided buffer has room for NUMBER_MAXIMUM_DIGITS_COUNT + 1 bytes. The number is aligned on the right and filled with ASCII '0' on the left to allow comparison with the number to find string.
 */
static inline void MainReadPlayerNumber(unsigned char *String_Number)
{
	unsigned char Character, i = 0, String_Unaligned_Number[NUMBER_MAXIMUM_DIGITS_COUNT + 1], j;
	
	// Display the user prompt
	SystemDisplayRenderTextString(STRINGS_INSERT_PLAYER_NUMBER);
	SystemDisplayUpdate();
	
	while (1)
	{
		Character = SystemKeyboardReadCharacter();
		
		switch (Character)
		{
			// Backspace
			case '\b':
				// There must be at least one character to remove
				if (i == 0) break;

				// Remove the character from the string
				String_Unaligned_Number[i] = 0;
				i--;
				
				// Display the backspace to erase the current line last character
				SystemDisplayRenderTextCharacter('\b');
				SystemDisplayUpdate();
				break;
				
			// New line
			case '\n':
				// Forbid empty string
				if (i == 0) break;
				
				// Add terminating zero
				String_Unaligned_Number[i] = 0; // 'i' contains the string length
				
				// Display the new line character
				SystemDisplayRenderTextCharacter('\n');
				SystemDisplayUpdate();
				
				// Shift the string to the right and fill leftmost empty digits with ASCII '0' to be able to compare the string with the random number one
				// Fill number beginning with zeroes
				for (j = 0; j < NUMBER_MAXIMUM_DIGITS_COUNT - i; j++)
				{
					*String_Number = '0';
					String_Number++;
				}
				// Copy number at the string end
				for (j = 0; j < i; j++)
				{
					*String_Number = String_Unaligned_Number[j];
					String_Number++;
				}
				// Terminate string
				*String_Number = 0;
					
				return;
				
			// Escape
			case SYSTEM_KEYBOARD_KEY_CODE_ESCAPE:
				SystemExitProgram();
			
			default:
				// Only digits are allowed
				if ((Character < '0') || (Character > '9')) break;
				
				// Make sure the maximum number size is not crossed
				if (i >= NUMBER_MAXIMUM_DIGITS_COUNT) break;
				
				// Append the digit to the string
				String_Unaligned_Number[i] = Character;
				i++;
				
				// Display the digit
				SystemDisplayRenderTextCharacter(Character);
				SystemDisplayUpdate();
				break;
		}
	}
}

//-------------------------------------------------------------------------------------------------
// Entry point
//-------------------------------------------------------------------------------------------------
void main(void)
{
	unsigned char String_Number_To_Find[NUMBER_MAXIMUM_DIGITS_COUNT + 1], String_Player_Number[NUMBER_MAXIMUM_DIGITS_COUNT + 1], Remaining_Attempts = PLAYER_MAXIMUM_ATTEMPTS_COUNT, i;
	signed char Result;
	
	SystemInitialize();
	
	while (1)
	{
		// Generate the number to find
		SystemRandomInitialize();
		MainGenerateRandomNumber(String_Number_To_Find);
		
		// Clean the display and return cursor to home
		SystemDisplayClear();
		
		while (1)
		{
			MainReadPlayerNumber(String_Player_Number);
			Remaining_Attempts--;
			
			// Is the player number the good one ?
			Result = strcmp((const char *) String_Player_Number, (const char *) String_Number_To_Find);
			// Player number is too small
			if (Result < 0) SystemDisplayRenderTextString(STRINGS_NUMBER_TOO_SMALL);
			// Player number is too big
			else if (Result > 0) SystemDisplayRenderTextString(STRINGS_NUMBER_TOO_BIG);
			// Player found the number
			else
			{
				SystemDisplayRenderTextString(STRINGS_PLAYER_WON);
				SystemDisplayUpdate();
				break;
			}
			
			// Display remaining attempts
			SystemDisplayRenderTextString(STRINGS_REMAINING_ATTEMPTS);
			SystemDisplayRenderTextString((const unsigned char *) itoa(String_Player_Number, Remaining_Attempts, 10)); // Recycle String_Player_Number
			SystemDisplayRenderTextCharacter('\n');
			SystemDisplayUpdate();
			
			// Did the player loose ?
			if (Remaining_Attempts == 0) 
			{
				SystemDisplayRenderTextString(STRINGS_PLAYER_LOST);
				SystemDisplayUpdate();
				break;
			}
		}
		
		// Wait for the player choice to start a new game or to quit
		while (1)
		{
			i = SystemKeyboardReadCharacter(); // Recycle 'i' variable
			if (i == '\n') break;
			if (i == SYSTEM_KEYBOARD_KEY_CODE_ESCAPE) SystemExitProgram();
		}
	}
}

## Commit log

2017-04-23 Initial commit. Made a led blink.
2017-04-24 Started system keyboard driver implementation. Keyboard raw scan codes are successfully received.
2017-04-25 Added AZERTY default key map to keyboard driver.
2017-04-26 Started hardware mother board schematics : added RS-232 UART and PS/2 keyboard connection.
    [Mother_Board.sch]
2017-05-01 Added LCD display module and SPI EEPROM to the schematics.
    [Mother_Board.sch]
2017-05-01 Added led and power supply to the schematics.
    [Mother_Board.sch]
2017-05-05 Added routed PCB.
    [Mother_Board.brd, Mother_Board.sch]
2017-05-19 Started graphic LCD display driver implementation. Display can be successfully initialized.
2017-05-19 Added SystemDisplayClear() function to the display driver.
2017-05-20 Added SystemDisplayBeginRendering() and SystemDisplayEndRendering() functions to the display driver and a 'pong ball' test in the 'find the number' application.
2017-05-20 Added SystemDisplayRenderSprite() function to the display driver.
2017-05-20 Started Pong application to test the display functions on a real case.
2017-05-22 Added system display frame timer functions.
2017-05-22 Used frame timer functions in the Benchmark application rendering loop to display whatever balls count with the same frame rate.
2017-05-29 Used a timer clocked by a non-stable oscillator to initialize the random numbers generator.
2017-05-30 Reorganized display control signals to be in the same order than the display module pins.
    [Mother_Board.sch]
2017-06-01 Used official TRIS registers bits names in keyboard and serial port drivers.
2017-06-01 Started system external EEPROM driver implementation, added SystemExternalEEPROMWritePage() function.
2017-06-03 Added sytem external EEPROM driver read page function and changed SPI clock polarity to make communication works.
2017-06-03 Fixed EEPROM SDI and SDO signals routing.
    [Mother_Board.brd, Mother_Board.sch]
2017-06-07 Added casing panel DXF files.
    [All_Panels.dxf, Bottom_Panel.dxf, Front_Panel.dxf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]
2017-06-08 Added digit sprites to the display driver.
2017-06-12 Added non-interrupt driven keyboard function needed by program manager application.
2017-06-14 Added system internal EEPROM driver.
2017-06-15 Added lowercase letter sprites to the system display driver.
2017-06-15 Used a constant to represent the escape key value in the system keyboard driver.
2017-06-15 Added a non-blocking function to the system serial port driver to tell whether a byte has been received.
2017-06-18 Put Programs Manager at the beginning of the program memory and relocated interrupts to jump into the application code. This is the safest way to allow to flash an application to the program memory w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
    [Main.c]
2017-06-18 Added microcontroller flash program memory driver to System.
2017-06-23 Fixed flash memory driver writing operation.
2017-06-23 Added reception overflow handling to the serial port driver (this avoids to hang the UART if an overflow condition is detected).
2017-06-23 Added led support to System.
2017-06-23 Turned led on when Programs Manager is executing time consuming tasks.
2017-06-23 Routed led to RC0 instead of RE3 (which is input-only pin).
    [Mother_Board.brd, Mother_Board.sch]
2017-06-24 Made Display system driver display a rectangle to indicate an unknown character.
2017-06-24 Added punctuation character sprites to the display driver.
2017-06-26 Added new line character support and screen scrolling when the text cursor reached the screen bottom to the display driver.
2017-06-26 Prevented control characters from being displayed in the display driver.
    [System_Display.c]
2017-06-26 Execute the screen scrolling code after the character has been displayed to avoid handling corner cases when a control character is typed at the end of a line.
    [System_Display.c]
2017-06-26 Added backspace support to display driver text mode. Sprites XOR rendering has been replaced by 'overwrite' rendering mode to make it work.
    [System_Display.c]
2017-06-30 Fixed bad register name in system serial port driver.
2017-07-09 Fixed Programs Manager keyboard hanging bug.
    [System_Keyboard.c]
2017-07-14 Added 'game' keys (arrows and space bar for now) support to the system keyboard driver.
2017-07-18 Improved applications and Programs Manager initializations (interrupts are no more enabled on the Programs Manager and clock is no more reconfigured on application start). Programs Manager seems to h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
2017-07-19 Added stuck world and 1-period oscillators detection to the Game of Life application.
    [Main.c]
2017-07-19 Added 3-period oscillators detection to the Game of Life application.
    [Main.c]
2017-10-25 Fixed AES substitution box and MixColumns() step in AES Test application.
    [Main.c]
2017-10-29 Used system led to show working activity in the AES Test application.
2017-11-15 Fixed a bug in the SystemDisplayRenderTextCharacter() function : '\b' character was not erasing the text at the good location.
    [System_Display.c]
2018-01-23 Started Space Avoiders application. Added classic Space Invaders game alien sprites.
    [Main.c]
2020-04-24 Fixed casing plates thickness picture bad file name.
